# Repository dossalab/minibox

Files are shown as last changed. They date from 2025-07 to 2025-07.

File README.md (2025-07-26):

## Minibox

This is a small Bluetooth receiver for remote controlled toys or small models. Receiver has 5 hobby servo / ESC outputs.
Since Xbox One's controller is essentially a Bluetooth gamepad, it is possible to bridge two together, turning them into a complete remote control solution.

### Connection

Switch your receiver and gamepad on. The LED on the receiver should start blinking quickly, indicating that it is in scanning mode. Once it will discover the controller it will start connecting automatically. If the connection is successful LED will turn off - then you're ready to go!

### Some considerations

- Range & reliability is probably not that great. It should be alright for cars and other ground vehicles but flying a drone like that could be dangerous (although I did);
- In case of inactivity (user is not interacting with the controller / not moving sticks), servos have to be reset to their initial position. That's because Xbox controller is designed for gaming, not for remote control. Once you stop moving sticks, controller enters low-power mode and stops sending data. Same happens when your model gets out of reach. It is hard for the receiver to distinguish these scenarios, so it has to disarm outputs in both cases (otherwise your model is at risk of running away :)

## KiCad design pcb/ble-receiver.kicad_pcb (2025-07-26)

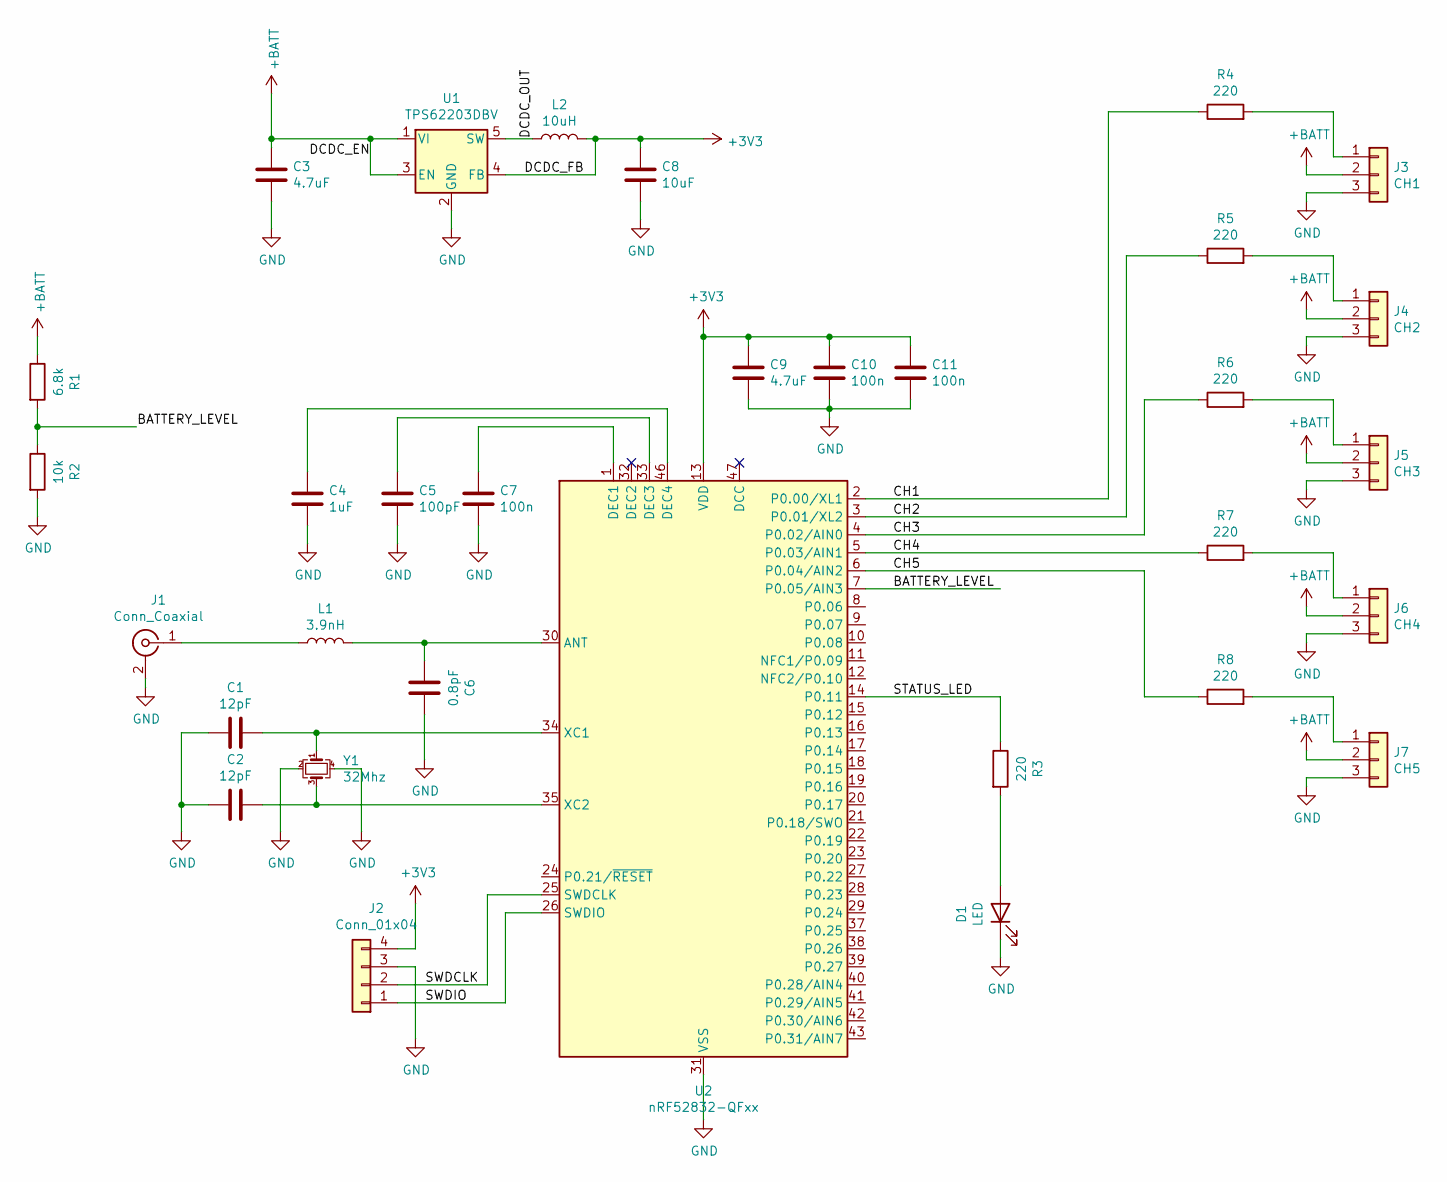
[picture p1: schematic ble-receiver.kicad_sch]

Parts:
C1, C2: 12pF; C_0603_1608Metric
C3, C9: 4.7uF; C_0603_1608Metric
C4: 1uF; C_0603_1608Metric
C5: 100pF; C_0603_1608Metric
C6: 0.8pF; C_0603_1608Metric
C7, C10, C11: 100n; C_0603_1608Metric
C8: 10uF; C_0603_1608Metric
D1: LED; LED_0603_1608Metric
J1: Conn_Coaxial; U.FL_Hirose_U.FL-R-SMT-1_Vertical
J2: Conn_01x04; PinHeader_1x04_P2.54mm_Vertical
J3: CH1; PinHeader_1x03_P2.54mm_Vertical
J4: CH2; PinHeader_1x03_P2.54mm_Vertical
J5: CH3; PinHeader_1x03_P2.54mm_Vertical
J6: CH4; PinHeader_1x03_P2.54mm_Vertical
J7: CH5; PinHeader_1x03_P2.54mm_Vertical
L1: 3.9nH; L_0603_1608Metric
L2: 10uH; L_0805_2012Metric
R1: 6.8k; R_0603_1608Metric
R2: 10k; R_0603_1608Metric
R3, R4, R5, R6, R7, R8: 220; R_0603_1608Metric
U1: TPS62203DBV; SOT-23-5
U2: nRF52832-QFxx; QFN-48-1EP_6x6mm_P0.4mm_EP4.6x4.6mm
Y1: 32Mhz; Crystal_SMD_2520-4Pin_2.5x2.0mm

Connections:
+3V3: C8.2, C9.2, C10.2, C11.2, J2.4, L2.2, U1.4 (FB), U2.13 (VDD), U2.36 (VDD), U2.48 (VDD)
+BATT: C3.2, J3.2, J4.2, J5.2, J6.2, J7.2, R1.1, U1.1 (VI), U1.3 (EN)
/BATTERY_LEVEL: R1.2, R2.1, U2.7 (P0.05/AIN3)
/CH1: R4.1, U2.2 (P0.00/XL1)
/CH2: R5.1, U2.3 (P0.01/XL2)
/CH3: R6.1, U2.4 (P0.02/AIN0)
/CH4: R7.1, U2.5 (P0.03/AIN1)
/CH5: R8.1, U2.6 (P0.04/AIN2)
/DCDC_OUT: L2.1, U1.5 (SW)
/STATUS_LED: R3.1, U2.14 (P0.11)
/SWDCLK: J2.2, U2.25 (SWDCLK)
/SWDIO: J2.1, U2.26 (SWDIO)
GND: C1.2, C2.2, C3.1, C4.1, C5.1, C6.1, C7.1, C8.1, C9.1, C10.1, C11.1, D1.1 (K), J1.2 (Ext), J2.3, J3.3, J4.3, J5.3, J6.3, J7.3, R2.2, U1.2 (GND), U2.31 (VSS), U2.45 (VSS), U2.49 (VSS), Y1.2, Y1.4
unnamed: D1.2 (A), R3.2
unnamed: J1.1 (In), L1.1
unnamed: J3.1, R4.2
unnamed: J4.1, R5.2
unnamed: J5.1, R6.2
unnamed: J6.1, R7.2
unnamed: J7.1, R8.2
unnamed: C6.2, L1.2, U2.30 (ANT)
unnamed: C7.2, U2.1 (DEC1)
unnamed: C5.2, U2.33 (DEC3)
unnamed: C4.2, U2.46 (DEC4)
unnamed: C1.1, U2.34 (XC1), Y1.1
unnamed: C2.1, U2.35 (XC2), Y1.3

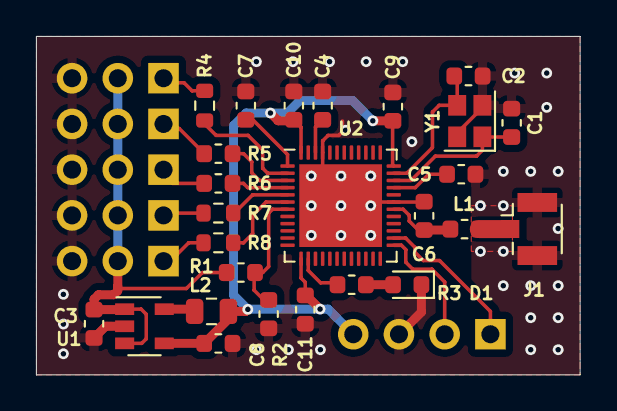
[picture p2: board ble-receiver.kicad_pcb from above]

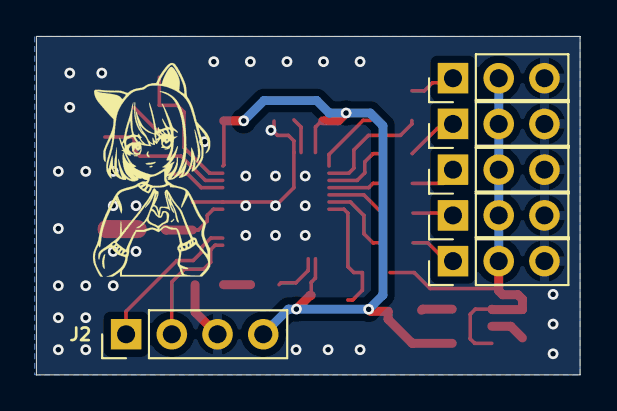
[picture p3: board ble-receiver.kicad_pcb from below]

Board: 2 copper layers, 30.2 x 18.8 mm, 32 parts (6 on the bottom side), 26 nets.

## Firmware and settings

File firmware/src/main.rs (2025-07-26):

#![no_std]
#![no_main]

use assign_resources::assign_resources;

use core::panic::PanicInfo;
use embassy_executor::Spawner;
use embassy_nrf::{interrupt, peripherals, Peri};
use embassy_sync::signal::Signal;
use git_version::git_version;
use indications::LedIndicationsSignal;
use nrf_softdevice::Softdevice;

use defmt::{info, unwrap};

mod ble;
mod indications;
mod xbox;

use defmt_rtt as _;

assign_resources! {
    led: LedResources {
        pwm: PWM0,
        led: P0_11
    },
    channels: ChannelResources {
        ch0: P0_00,
        ch1: P0_01,
        ch2: P0_02,
        ch3: P0_03,
        ch4: P0_04,
    },
    battery: BatteryResources {
        battery: P0_05
    },
}

// It's safer to reboot rather than hang
#[panic_handler]
fn panic(_info: &PanicInfo) -> ! {
    cortex_m::peripheral::SCB::sys_reset();
}

fn hw_init() -> (AssignedResources, &'static Softdevice) {
    let mut config = embassy_nrf::config::Config::default();

    /*
     * Softdevice implicitly utilizes the highest-level interrupt priority
     * We have to move all other interrupts to lower priority, unless
     * random issues and asserts from the Softdevice may (and will) occur
     */
    config.gpiote_interrupt_priority = interrupt::Priority::P2;
    config.time_interrupt_priority = interrupt::Priority::P2;

    let p = embassy_nrf::init(config);
    let sd = Softdevice::enable(&nrf_softdevice::Config::default());

    (split_resources!(p), sd)
}

#[embassy_executor::main]
async fn main(spawner: Spawner) {
    let (r, sd) = hw_init();

    info!("minibox ({}) is running. Hello!", git_version!());

    static LED_INDICATIONS_SIGNAL: LedIndicationsSignal = Signal::new();

    unwrap!(spawner.spawn(indications::run(&LED_INDICATIONS_SIGNAL, r.led)));
    unwrap!(spawner.spawn(ble::run(sd, &LED_INDICATIONS_SIGNAL)));

    sd.run().await
}

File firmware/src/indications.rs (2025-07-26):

use core::future;

use defmt::{error, info, unwrap};
use embassy_futures::select::{select, Either};
use embassy_nrf::pwm::{self, SequenceConfig, SequencePwm, SingleSequenceMode, SingleSequencer};
use embassy_sync::{blocking_mutex::raw::CriticalSectionRawMutex, signal::Signal};

use crate::LedResources;

#[derive(Copy, Clone)]
pub enum IndicationStyle {
    Disabled,
    BlinkFast,
    BlinkSlow,
}

pub type LedIndicationsSignal = Signal<CriticalSectionRawMutex, IndicationStyle>;

async fn run_sequencer<'a, T>(
    pwm: &mut SequencePwm<'a, T>,
    sequence: &[u16],
    refresh: u32,
) -> Result<(), pwm::Error>
where
    T: pwm::Instance,
{
    let mut sequence_config = SequenceConfig::default();
    sequence_config.refresh = refresh;

    let sequence = SingleSequencer::new(pwm, sequence, sequence_config);
    sequence.start(SingleSequenceMode::Infinite)?;

    Ok(future::pending().await)
}

#[embassy_executor::task]
pub async fn run(signal: &'static LedIndicationsSignal, r: LedResources) {
    info!("led indications running...");

    let pwm_config = pwm::Config::default();
    let mut pwm = unwrap!(SequencePwm::new_1ch(r.pwm, r.led, pwm_config));

    let sine_sequence = [
        500, 598, 691, 778, 854, 916, 962, 990, 1000, 990, 962, 916, 854, 778, 691, 598, 500, 402,
        309, 222, 146, 84, 38, 10, 0, 10, 38, 84, 146, 222, 309, 402,
    ];

    let mut do_indications = async |x| match x {
        IndicationStyle::Disabled => future::pending().await,
        IndicationStyle::BlinkFast => run_sequencer(&mut pwm, &sine_sequence, 7).await,
        IndicationStyle::BlinkSlow => run_sequencer(&mut pwm, &sine_sequence, 20).await,
    };

    let mut style = IndicationStyle::Disabled;

    loop {
        let ret = select(signal.wait(), do_indications(style)).await;
        match ret {
            Either::First(new_style) => style = new_style,
            Either::Second(r) => {
                if r.is_err() {
                    error!("unable to start new sequence");
                }
            }
        }
    }
}

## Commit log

2024-03-23 basic demo with motors & stuff
2024-07-10 switch to reset the board
    [main.rs]
2025-07-26 add PCB
    [ble-receiver.kicad_pcb, ble-receiver.kicad_sch]
2025-07-26 bump kicad version
    [ble-receiver.kicad_pcb, ble-receiver.kicad_sch]
